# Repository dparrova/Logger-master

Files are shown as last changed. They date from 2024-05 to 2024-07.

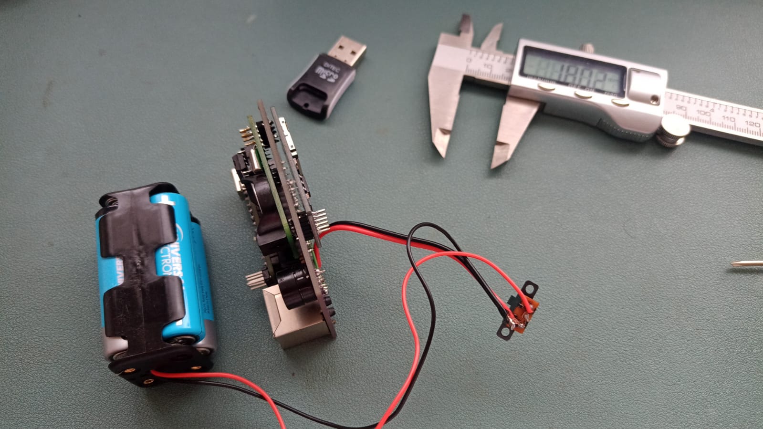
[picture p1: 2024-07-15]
Archivos/Fotos/BoardEnsamble.jpeg

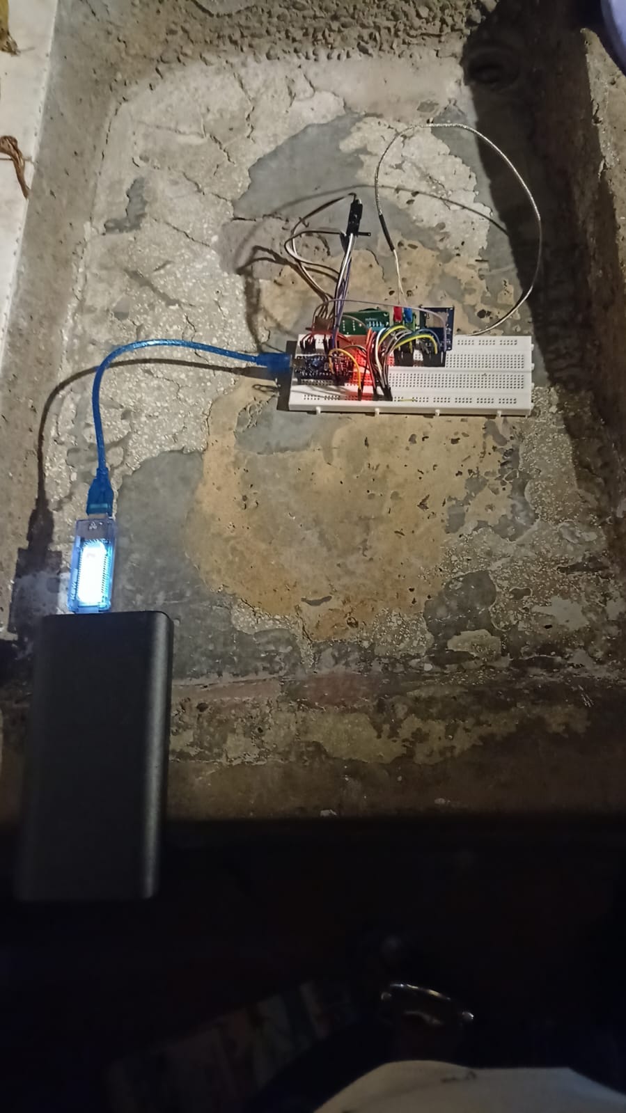
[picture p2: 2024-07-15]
Archivos/Fotos/Prototipo.jpeg

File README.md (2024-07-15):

# Datalogger Secador de alimentos
## Contenido
En este repositorio encontrará:

* Lista de componente
* Esquematicos / Archivos
  * Archivo PCB para fabribar
  * Archivo de para subir al arduino
  * Archivos del modelo 3D de la caja
* Funcionamiento
* Sonidos
* Errores
* repositorio https://github.com/dparrova/Logger-master 

## Listado de componentes
para el desarrollo del Datalogger se usaron los siguiente modulos

* placa de Arduino Nano
* modulo de RTC
* modulo de Micro SD
* modulo DTH11
* modulo de sensor de temeratura MAX667
* micro SD
* conecotr de RJ45
* cable de dato upt RJ45

## Esquematicos / Archivos
Dendro de la carpeta de Archivos se encuentran los esquematicos, modelos de la caja en archivos STL para la impreción en 3D, tambien los archivo Gerber para la impresión de la placa.

## Funcionamiento
El dispositivo cuenta con alimentación proporcinada por cuatro baterias AA. Almacena datos cada minuto de dos temperaturas, una humedad relativa y la fecha y hora de cada dato. Emite sonidos de como idicador de errores o procesos satisfactorios, se neciende y apaga con el interrutor lateral.

### Crear archivo Datos.csv 
Teniendo la memoria dentro del dispositivo, se verifica que exista el archivo Datos.csv, si no existe, lo crea automaticamente y comienza a guardar datos.

### Procedimiento de apagado/encendido
Apague o encienda el dispositivo con el interruptor ubicado en la parte lateral.

### Procedimdiento de toma de datos
Primero coloque las baterias en el porta baterias. 
Coloque tambien la memoria microSD en la ranura. Esta memoria debe tener en su interior un archivo llamado Datos.csv.
Conecte el cable de datos al dispositivo mediante el conector de red.
Encienda el dispositivo con el interruptor ubicado en la parte lateral.
El dispositivo realizara sonidos (ver la sección de *sonidos*)
Los datos se tomaran cada minuto

### Recolección de datos
Con el dispositivo apagado, retire la memoria microSD del dispositivo, use un adaptador microSD/USB para transferir los datos al computador, haga una copia del archivo Datos.csv a su equipo.

Asegurese de no abrir directamente el archivo que se encuentra en memoria desde Excel o cualquier otro programa que modifque el tipo de archivo.

## Sonidos
Se integra un buzzer para tener una ayuda auditiva para identificar acciones
* Un pitido (cada minuto) : indica que el dispositivo almacenó los datos correctamente, este tiene un intervalo de un minuto
* Dos pitidos (repetitivos) : indica que no encuentra la memora microSD conectada o que hay un error.

### Errores comunes
* Reconoce el archivo Datos.csv pero no guarda información
  * Solución: elimine el archivo y vuelvalo a crear.
* Alacena datos pero con el errores en la fecha
  * Solución : configurar el reloj,
  * Remplace la bateria y compile de nuevo el archivo al arduino.
* En cada reinicio del dispositivo se desconfigura la fecha y hora
  * Cambiar la bateria del RTC, esto se hace abriendo la caja y cambiado la bateria redonda.

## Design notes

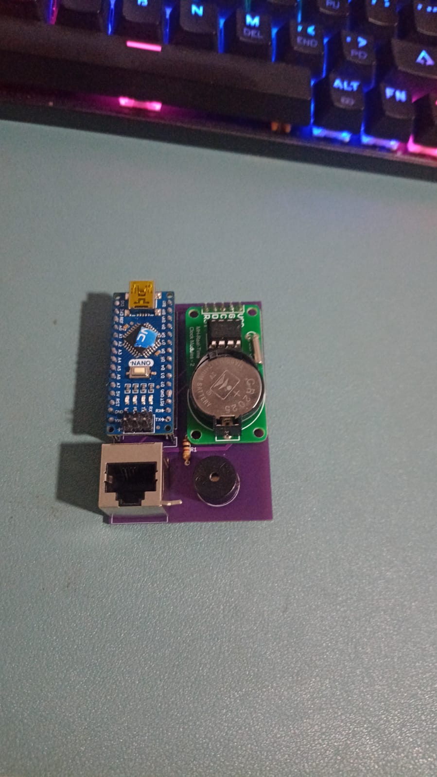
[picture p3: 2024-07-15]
Archivos/Fotos/BoardFinal.jpeg

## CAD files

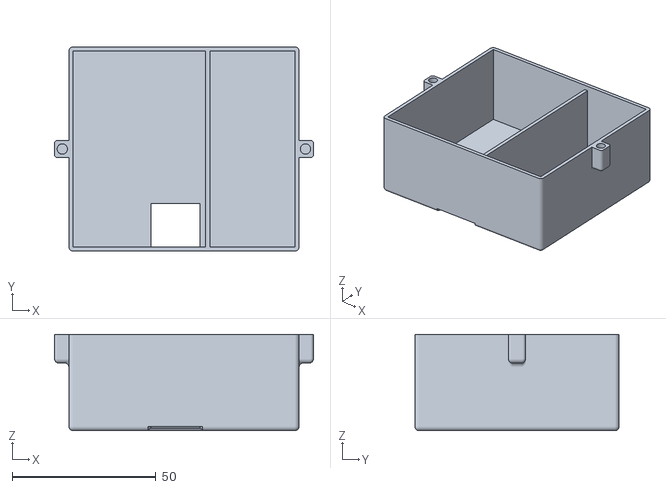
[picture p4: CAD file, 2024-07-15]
Archivos/STL/UNAL-Erika-Tatiana-Caja.stl
90.0 x 71.0 x 33.5

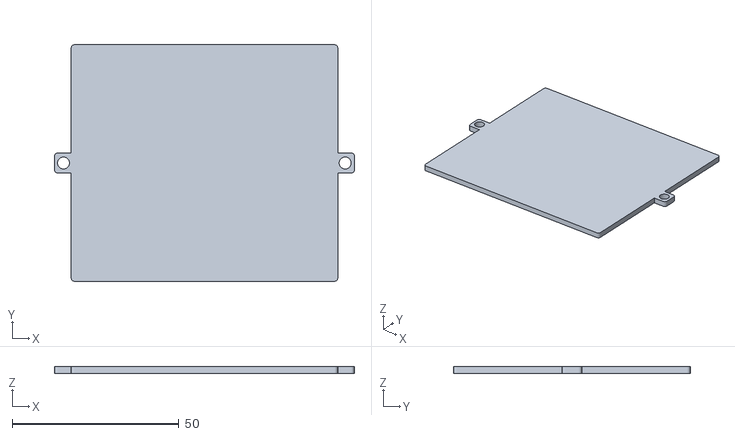
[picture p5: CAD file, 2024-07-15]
Archivos/STL/UNAL-Erika-Tatiana-Tapa.stl
90.0 x 71.0 x 2.00

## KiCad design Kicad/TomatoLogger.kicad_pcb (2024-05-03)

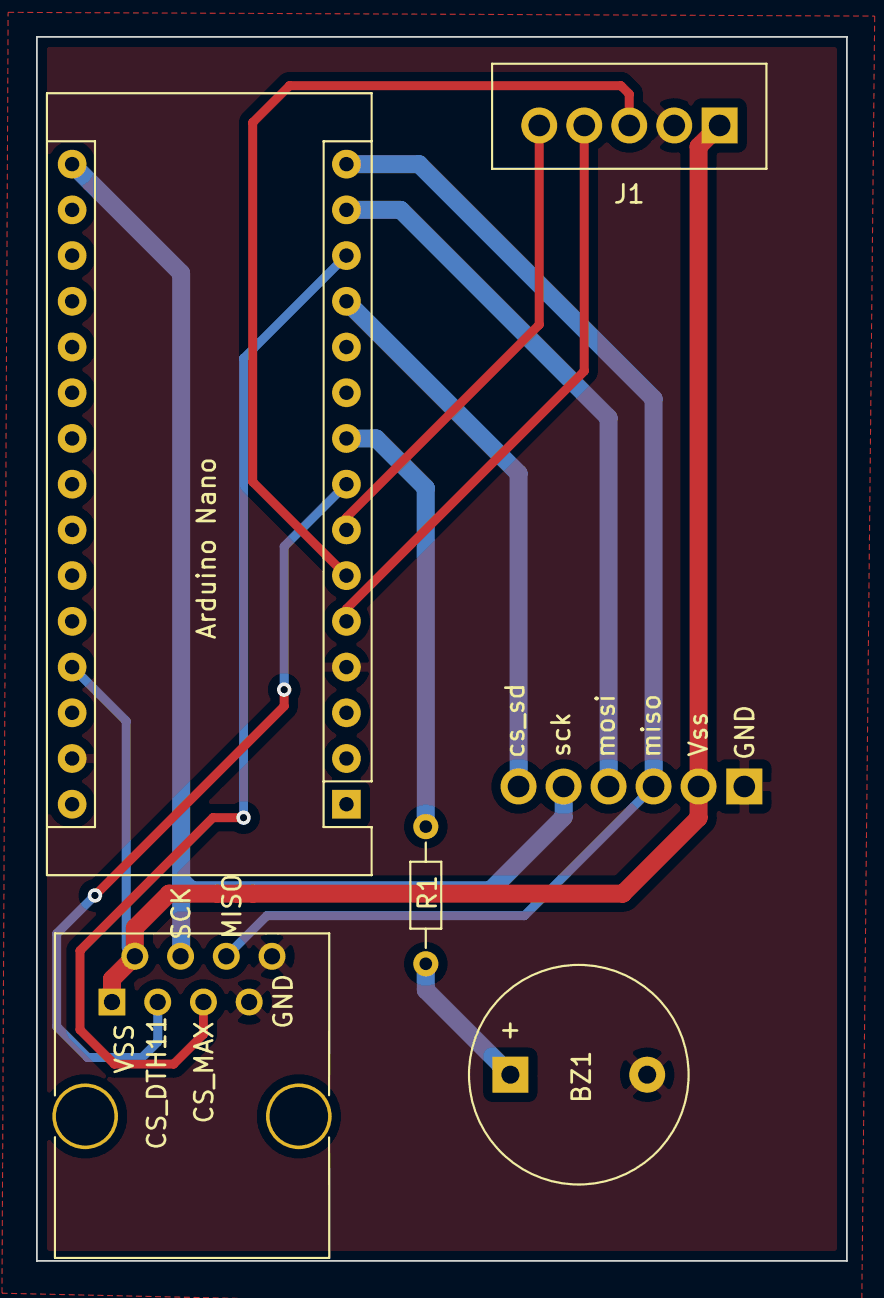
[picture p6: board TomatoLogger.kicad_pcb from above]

Board: 2 copper layers, 45.0 x 68.0 mm, 6 parts (1 on the bottom side), 13 nets.

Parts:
Arduino Nano: Arduino_Nano_v2.x; Arduino_Nano
BZ1: Buzzer; Buzzer_12x9.5RM7.6
J1: RCT; Wafer_Vertical15x5.8x7RM2.5-5
J2: SD; Wafer_Vertical17.5x5.8x7RM2.5-6
J3: SENSOR; RJ45_8
R1: R; R_Axial_DIN0204_L3.6mm_D1.6mm_P7.62mm_Horizontal

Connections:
5V: Arduino Nano.27, J1.1, J2.2, J3.1, J3.2
Buzzer: Arduino Nano.9, R1.1
CLK: Arduino Nano.6, J1.3
CS_DTH11: Arduino Nano.8, J3.3
CS_MAX: Arduino Nano.13, J3.5
CS_RCT: Arduino Nano.5, J1.4
CS_SD: Arduino Nano.12, J2.6
GND: Arduino Nano.4, Arduino Nano.29, BZ1.2, J1.2, J2.1, J3.7, J3.8
MISO: Arduino Nano.15, J2.3, J3.6
MOSI: Arduino Nano.14, J2.4
unnamed: BZ1.1, R1.2
RST: Arduino Nano.7, J1.5
SCK: Arduino Nano.16, J2.5, J3.4

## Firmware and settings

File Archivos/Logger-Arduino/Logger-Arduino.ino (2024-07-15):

 /* 
Created in 20-may-2023 for Arduino Nano Boards
Modified by DiegoCh 
For some Arduino Nano board use 
File->Preferences menu, click on the little icon to the right of the Additional Boards Manager URLs: and add this line after any that are already present (or as the first line if you’ve never added any before):
https://raw.githubusercontent.com/dbuezas/lgt8fx/master/package_lgt8fx_index.json
Tools->Board: Boards Manager… window type LGT8fx in the filter/search box, and you should see LGT8Fx Boards.
*/

// CONNECTIONS:
// DS1302 CLK/SCLK --> 3
// DS1302 DAT/IO --> 2
// DS1302 RST/CE --> 4
// DS1302 VCC --> 3.3v - 5v
// DS1302 GND --> GND

#include <ThreeWire.h>  
#include <RtcDS1302.h>
#include <SoftwareSerial.h>
#include <DHT.h>
#include <DHT_U.h>
#include <MAX6675.h>


#include <SPI.h> //librerias para SD
#include <SD.h>

#define DHTTYPE DHT11
#define DHTPIN 5    

#define ssr_pin 8
#define CS_PIN 10
#define CS_PIN_SD 9 
#define PIN_BUZZER 6
  
File myFile;
File myFileDate;

char fileName[] = "Datos.csv";
char fileNameDate[] = "fecha.txt";
char fileConf[]= "conf.cfg";
char texto[]="";

char Fecha;
float h;
float t;
float temperatura;

ThreeWire myWire(2,3,4); // IO, SCLK, CE
RtcDS1302<ThreeWire> Rtc(myWire);
DHT dht(DHTPIN, DHTTYPE);
MAX6675 tcouple(CS_PIN);

void setup () 
{
    Serial.begin(115200);

    Serial.print("compiled: ");
    Serial.print(__DATE__);
    Serial.print(" ");
    Serial.println(__TIME__);

    

    Rtc.Begin();
    dht.begin();

    RtcDateTime compiled = RtcDateTime(__DATE__, __TIME__);
    printDateTime(compiled);
    Serial.println();

    if (!Rtc.IsDateTimeValid()) 
    {
        // Common Causes:
        //    1) first time you ran and the device wasn't running yet
        //    2) the battery on the device is low or even missing

        Serial.println("RTC lost confidence in the DateTime!");
        Rtc.SetDateTime(compiled);
    }

    if (Rtc.GetIsWriteProtected())
    {
        Serial.println("RTC was write protected, enabling writing now");
        Rtc.SetIsWriteProtected(false);
    }

    if (!Rtc.GetIsRunning())
    {
        Serial.println("RTC was not actively running, starting now");
        Rtc.SetIsRunning(true);
    }

    RtcDateTime now = Rtc.GetDateTime();
    if (now < compiled) 
    {
        Serial.println("RTC is older than compile time!  (Updating DateTime)");
        Rtc.SetDateTime(compiled);
    }
    else if (now > compiled) 
    {
        Serial.println("RTC is newer than compile time. (this is expected)");
    }
    else if (now == compiled) 
    {
        Serial.println("RTC is the same as compile time! (not expected but all is fine)");
    }

    //Tarjeta MicroSD 

   if (SD.begin(CS_PIN_SD))
    {
    Serial.println("SD card is present & ready");
    
    if (SD.exists(fileName)) //Comprobar si archivos Datos Existe
    {
      Serial.println("Archivo Datos existe");
    }
    else{
        myFile = SD.open(fileName,FILE_WRITE);
        if(myFile){
        myFile.println("Dia,Hora,Humedad,Temperatura1,Temperatura2,DeltaTemperatura");
        myFile.close();
         }
        }      
    } 
    
    else
    {
    Serial.println("SD card missing or failure");
    buzzer("Error");
    }
}

void loop () 
{
    
    RtcDateTime now = Rtc.GetDateTime();
    float h = dht.readHumidity()+4 ;
    float t = dht.readTemperature()-6 ; //Ambiente
    float temperatura   = tcouple.readTempC()-4; //Secador
    delay(1000);
    float DetalT = temperatura - t;

    String datos = printDateTime(now)+"," +String(h) + "," + String( t )+ "," + String( temperatura)+ "," + String(DetalT);
    Serial.println(datos);
   
    writeToFile(datos);
    delay(58000); // 60 segundos
    if (!now.IsValid())
    {
        // Common Causes:
        //    1) the battery on the device is low or even missing and the power line was disconnected
        Serial.println("RTC lost confidence in the DateTime!");
    }

   
}

#define countof(a) (sizeof(a) / sizeof(a[0]))

String printDateTime(const RtcDateTime& dt)
{
    char datestring[20];
    snprintf_P(datestring, 
            countof(datestring),
            PSTR("%02u/%02u/%04u,%02u:%02u:%02u"),
            dt.Month(),
            dt.Day(),
            dt.Year(),
            dt.Hour(),
            dt.Minute(),
            dt.Second() );
   return datestring;
}

void writeToFile(String data)
{
  if(SD.exists(fileName)){
  myFile = SD.open(fileName, FILE_WRITE);
  if (myFile) // it opened OK
    {
    myFile.println(data);
    myFile.close(); 
    buzzer("Done");
    }
  else {
    Serial.println("Error opening file");
    buzzer("Error");
    }
  }
  else{
     buzzer("Error");
    }
}



void buzzer(String tipo)
{
  if(tipo == "Done"){
  tone(PIN_BUZZER,880);
  delay(500);
  noTone(PIN_BUZZER);
  }
  else{
    Serial.println("Error");
    while(1){ 
   //   tone(PIN_BUZZER,880);
   //   delay(200);
   //   noTone(PIN_BUZZER); 
   //   delay(100);  
   //   tone(PIN_BUZZER,880);
   //   delay(200);
   //   noTone(PIN_BUZZER);
   //   delay(300);
      }
    }
}

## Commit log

2024-05-03 frist commint
    [TomatoLogger.kicad_pcb, TomatoLogger.sch]
2024-07-15 Archivos STL agregados
    [UNAL-Erika-Tatiana-Caja.stl, UNAL-Erika-Tatiana-Tapa.stl]
